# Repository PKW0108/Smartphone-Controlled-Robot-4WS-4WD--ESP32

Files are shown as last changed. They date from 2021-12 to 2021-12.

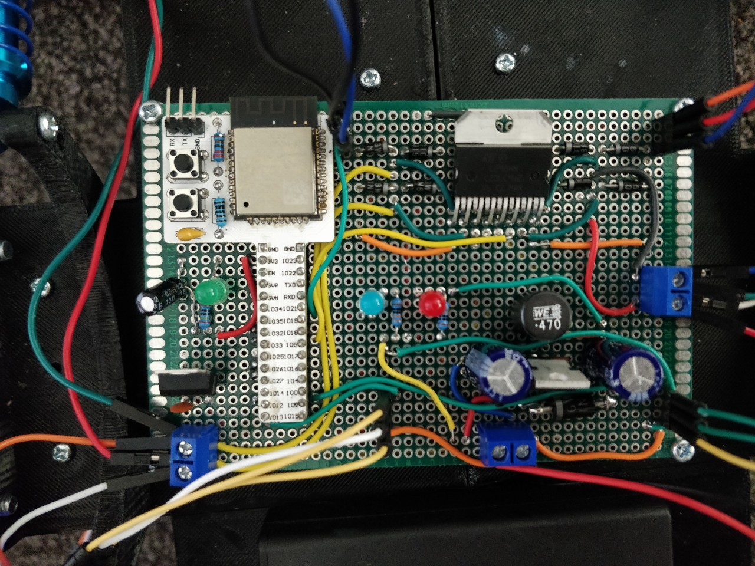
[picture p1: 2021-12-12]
PCB.jpg

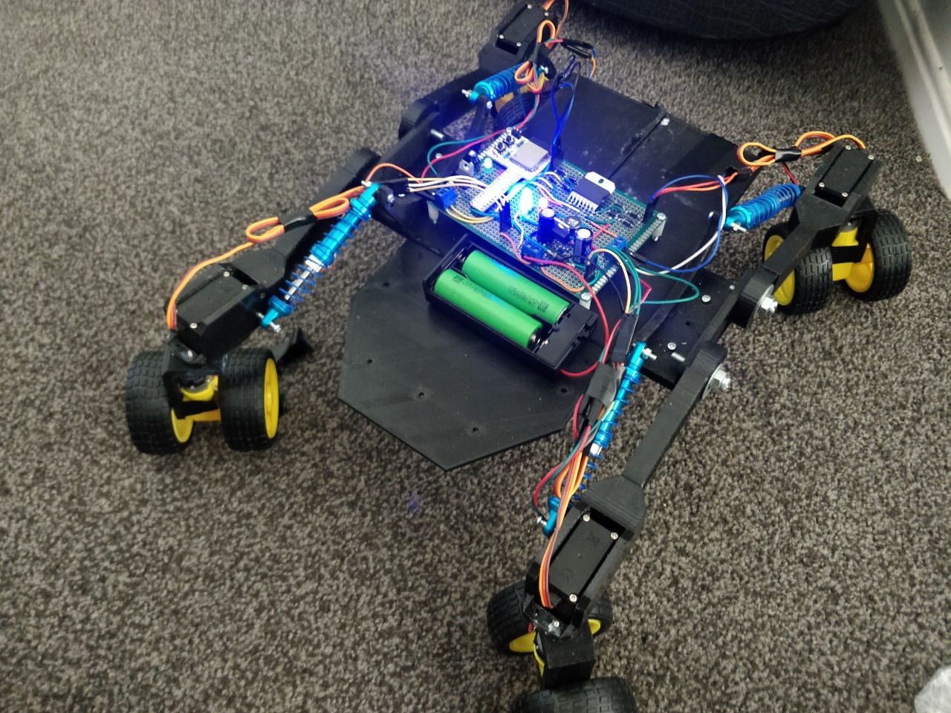
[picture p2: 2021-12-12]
Prototype Robot.jpg

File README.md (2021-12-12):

# Smartphone-Controlled-Robot-4WS-4WD--ESP32
Final Semester Project for Unitec Institue of Technology.

These are codes and 3D modellings I have created for my final semester project at Unitec Institute of Technology.

I have created an Android App using MIT App Inventor and custom PCB board that includes modules such as motor driver, buck converter and ESP32 micro-controller. The ESP32 will use its Bluetooth feature for the connection.

The Prototype Robot has 4DC motors and 4 Servo motors to meet the mobility objective. The Android App has various steering modes for the servos to move to its desired positions.

Please read the Report for more detailed analysis of this project.

Thank you

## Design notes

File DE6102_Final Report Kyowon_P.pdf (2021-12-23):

## Mobile Controlled Robot(4WD/4WS) for agricultural use

Engineering Project Report

New Zealand Diploma in Engineering (Electrical)

Department of Electrotechnology

Unitec Institute of Technology

Kyowon Park

2021

Page | i

## Declaration of Originality

This report is my own unaided work and was not copied from nor written in

collaboration with any other person.

Name: Kyowon Park

Page | ii

## Abstract

Growth in population has been a problem in farming industry for several years and the

agricultural robots started developing around 1920s. The number of workers required

on the field are becoming more insufficient around the world. There are many

agricultural robots that can perform tasks such as weed spraying, seed planting and

harvesting. My project aims to aid in agriculture by making a prototype robot that can

provide a platform for various agrobot projects to be attached. The methodology

approach was to research online to gather information on parts required and

experimenting with the information. This robot is easy for people to use by just simply

connecting with Bluetooth on smartphone. One custom built prototype PCB has all

the modules that are needed for this robot which includes modules such as

microcontroller, voltage regulators and motor driver. Advantage of this PCB is that it

can have supply voltage up to 24V DC where the robot can be easily modified for

more power, speed and longer lasting. The use of 4 servo motors for each wheel allows

the robot to have independent steering and give great advantage of moving freely in

small areas like green house. My robot aims for user to easily modify hardware and

software and not only can this be used in agriculture, but it can provide wide range of

application.

Page | iii

## Acknowledgements

I would like to thank lecturer Deepiner Sidhu for providing and giving ideas for this

project. I also would like to thank Dr Momen Bahadornejad for leading this paper.

Special thanks to my friend for lending me his 3D printer for constructing my

prototype. Thanks to my families for their support, encouragement and feedbacks for

improvements. Finally, I would like to thank lecturer Anthony Lai and Dr Nigel Yee

for attending to my presentation and demonstration session.

Page | iv

## Table of Contents

Table of Contents

Page | v

Page | vi

## List of Figures

## Chapter One: Introduction

### 1.1 Background

Agricultural robot started developing around 1920 and automatic vehicle was

implemented into agriculture between 1950s and 60s. In recent years, the population

around the world has increased rapidly where the demand for crops or food grown in

farms has increased. The problem is that the shortage of workers is increasing as time

goes on.

### 1.2 Aims and Significance of the project

The aim of my project is to build a prototype smart phone controlled robot vehicle that

will provide a platform for other projects such as LED weed detector for agricultural

use. My project will have four individual steering mechanism which allows the robot

to move freely in many directions without having to move its body. New Zealand

farmers relies on quad bikes for their farm vehicles where 80 000 to 100 000 quad

bikes are used in NZ. Despite the fast transportation and the ability to attach

accessories like sprayer, the quad bike has many problems. The driver is required to

wear safety outfit due to the harmful chemicals that herbicide contain, and the

accidents caused by the quad bikes are significant where 346 quad bike accidents

reported between 2012 to 2018.

Remote controlled vehicles can eliminate these problems and aid in the agriculture

crisis that is currently happening. Robots do not get tired and can get a lot more jobs

completed which can solve labouring issues.

### 1.3 Structure of the report

Introduction chapter has briefly articulated the background of the research and the aim

and significance of the project. The literature review briefly explains the history and

the current work of agricultural robot. The methodology chapter outlines the methods

and processes used to conduct the project. The final chapter concludes the results of

the project and provides recommendations for future studies.

## Chapter Two: Literature Review

Robotics technology including the agricultural robot is advancing. Development of

autonomous agricultural vehicles were developed in 1950s and it was not until the

1980s when the computer technology was implemented into the agricultural robot.

MAR-1 Agricultural Robot was developed in the early 1980s at Moscow Institute of

Agricultural Engineers (figure 1). MAR-1 was made for cattle-breeding industry and was

developed so it can perform autonomous entering and exiting of the site.

There are many types of agricultural robots in modern days equipped with advanced

technology. However, there lots of future works for these robots for example, robot

sensor cannot identify a certain type of plants or fruits for harvesting and fruits do not

grow from the branches identically. Most of the agricultural robots are designed for a

certain tasks and must be replaced or purchase another type of robot for different tasks.

In New Zealand, the Robotics Plus is currently developing Unmanned Ground Vehicle

(figure 2.2) to be used in the orchard field. This project is collaborated with university

of Auckland and Waikato. This vehicle aims to carry their various agricultural projects

such as the harvester and navigate through the orchard autonomously. A disadvantage

of this vehicle is that it only has two wheel steering system which can only be operated

in the large open areas.

Figure 2.1 -first model of MAR-1 (Robot, 2012)

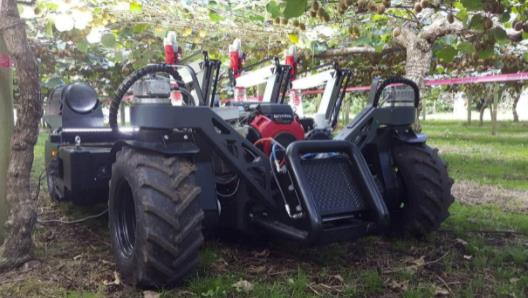
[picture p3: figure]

Figure 2.2- UGV by Robotics Plus (Harris, 2020)

## Chapter Three: Methodology

This chapter will explain the methodology that was used to complete designing and

constructing of prototype. This project was completed by using internet to gather

information and carrying out experiments. There were three main steps which were

planning, testing and evaluation.

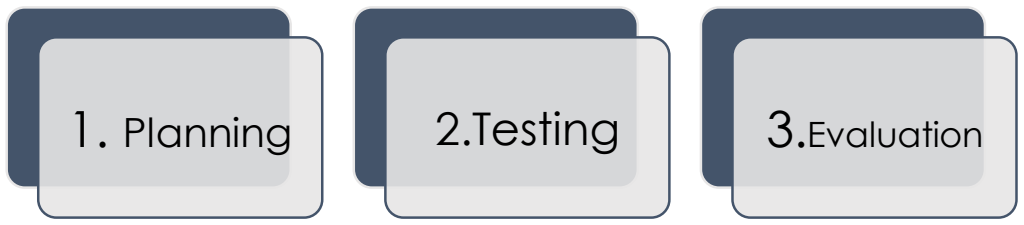
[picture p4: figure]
1. Planning; 2.Testing; 3.Evaluation

Figure 3-Project Steps

### 3.1 Planning

First step was to identify the main functions and objective for my project and then

decide on the requirements for the hardware and software. There were three main

objectives for the project which were: controlled using smart phone by Bluetooth

connection, can steer in different modes and powered by batteries. Once the objectives

were identified, I carried out research on mobile controlled robot online to gather

information on the components and design ideas of the prototype. Figure below is the

hardware design.

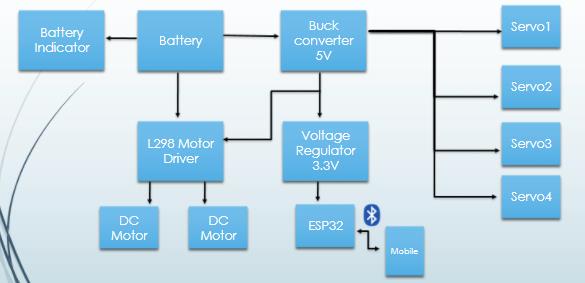
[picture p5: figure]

Figure 3.1-Hardware design

3.2 Hardware

The aim for selecting parts were to meet the budget of under $200 and be able to

perform the main functions to meet the objectives. Below is the list of the hardware

that was used to complete this project.

Part/component | Qty | Seller | Cost ($NZD)
ESP32 | 1 | Trademe | 13.99
L298 IC | 1 | Trademe | 4.99
LM2596 | 1 | DigiKey | 6.12
LD1117 3.3V | 1 | DigiKey | 0.70
Inductor 47uH 3A | 1 | DigiKey | 2.46
Dc motor with wheels | 4 | Trademe | 47.6
18650 battery holder | 1 | Trademe | 3.99
PCB board 120mm x 80mm | 1 | Trademe | 4.99
Pin header 1x3 | 4 | Trademe | 2.50
2 Pin Terminal Block(10pc) | 1 | Trademe | 3.99
Jumper Wire pack | 1 | Trademe | 8.99
330uf 35V | 2 | Surplustronics | 0.70
MG995 servo motor | 4 | Amazon | 28.09
MISC | | | 30
| | | Total 158.41
Table 3 – Component list table

### 3.2.1 Main components

TT DC motor
This is a generic 3-6V DC motor for simple robotics and affordable. There was no

need for more powerful motors for this prototype as its main objective can be made

with TT DC motors.

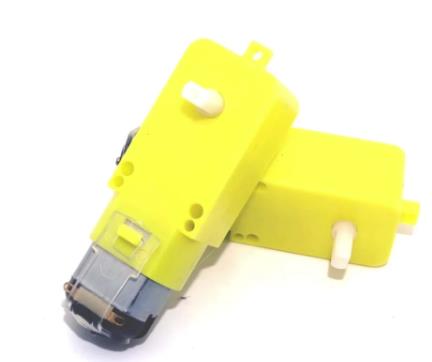
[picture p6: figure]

Figure 3.2-TT DC motor

Battery
Two Li-ion rechargeable batteries were the main supply which is 8.4V when fully

charged. The supply can be upgraded up to 24V if needed.

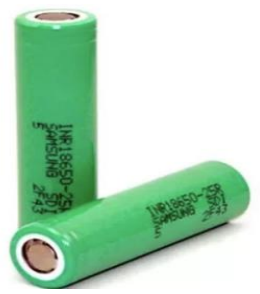
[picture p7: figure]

Figure 3.3-Li-ion 3.7V battery

LM2596

LM2596 is a simple switching power converter which can have an input up to 45V

DC and step down to 5V DC with 3A output current. Supplying more than 24V is not

recommended as the efficiency of the converter drops and will have heating problem.

The model used for this prototype is the fixed 5V version and has the efficiency of 80%

with 12V input. The 5v is required by the servo motors and the IC input of L298 motor

driver.

L298

The L298 is a dual h-bridge motor driver which can have maximum input voltage of

46V and has output current of 2A. It is recommended that diodes are used at the output

Figure-3.4LM2596 5V as this IC does not have internal protection for inductive load. This motor driver was

used so this prototype can be upgraded to 12V DC motors.

Figure 3.5-L298HN motor driver

ESP 32

The ESP 32 has built in Bluetooth and Wi-Fi feature and is known for its low power

consumption. ESP32 has the Bluetooth 4.2 and its range can be up to 50 meters

outdoors and about 10 meters indoors. It is recommended to use 10uf and 0.1uf

decoupling capacitor in parallel at the 3.3V pin to avoid brown out issues. ESP32

features 34 GPIO pins and 18 analog channels. This prototype will be using 10 analog

channels.

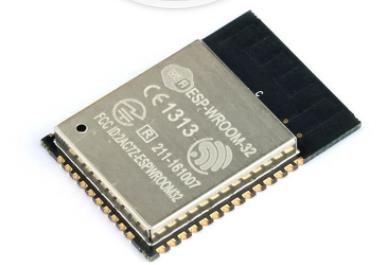
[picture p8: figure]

Figure 3.6-ESP32 wroom 32

MG995 Servo motor
By using one servo motor for each wheel can allow the robot to have individual

steering feature. MG995 is affordable and provide good amount of strength where

each motor can lift around 9.4kg/cm when operating at 5V.

Figure 3.7-MG995 servo motor

### 3.3 Software

The required software to design the prototype including android app and PCB were

OnShape, Arduino IDE, Easy EDA and MIT App inventor.

### 3.3.1 OnShape

OnShape is a free online software for 3D designing and it is very similar to Solid

works. I used this software to design the body and wheel attachments. The requirement

for the robot would be to have a ground clearance from the body of the robot and to

have four legs to hold servos and the DC motors. There are four main parts that were

designed using OnShape, base, arms, legs and holder. The base was a general flat

platform for the PCB and battery to be placed on top. Figure below is the finished 3D

design of the prototype robot.

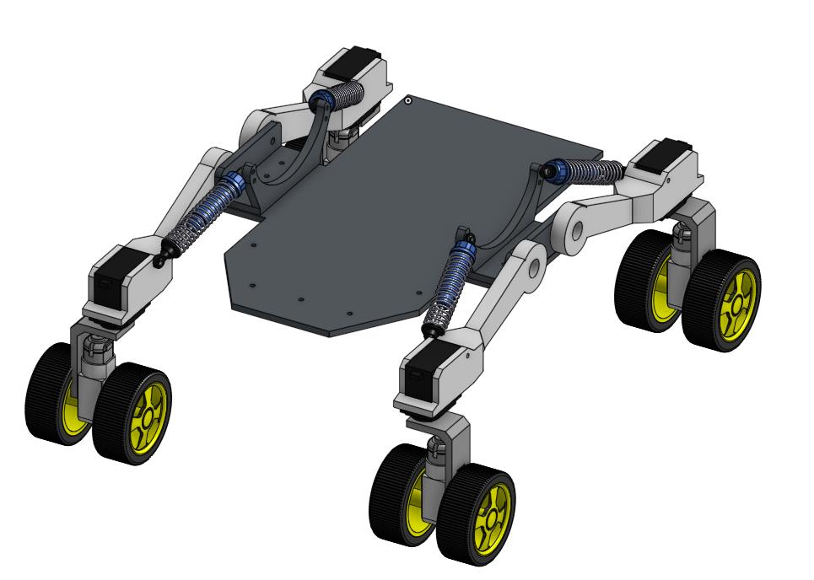
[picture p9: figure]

Figure 3.8- 3D design of the robot

### 3.3.1.1 Arms

Arms will hold the servos in place and there were errors during designing stage where

the servos did not quite fit properly at the first attempt (figure 3.9) and adjustment had

to be made.

Figure 3.9

Another issue of the design was that the arms holding the servos were unstable when

turning and this was fixed by placing the shock absorber to hold the arms and the body

together.

### 3.3.1.2 Legs

The leg is designed so that the DC motors can sit in upright position to give more

height for the robot. The leg attaches to the servos, so it can be moved according to

the servo angles.

Figure 3.11-Designed leg | Figure 3.12-assembled leg

Figure 3.10

### 3.3.1.3 Holder

Due to the length of the arm, the arms were very unstable when turning, it would

wobble around sideways without any support. The arm holder will hold the shock

absorber and the arms together to give more stability when the robot is moving. M5

screws are used for the arms and the size of the shock absorber is 1/10 RC 90mm

shock absorber. The extra holes on the horn looking design is for giving options to

change the size of shock absorber.

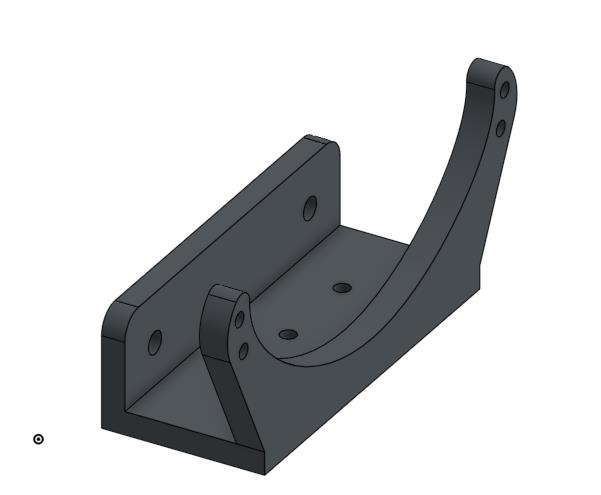
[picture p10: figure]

Figure 3.13-Designed holder

Figure 3.14-assembled holder

### 3.3.2 Arduino IDE

Arduino IDE was the software used for coding and programming the ESP32. First step

was to define variables and attach motors to ESP32 output pins. Once the motors were

attached to the pins, next step was to set up Bluetooth connection and analogue

channels for all motors (figure 3.15).

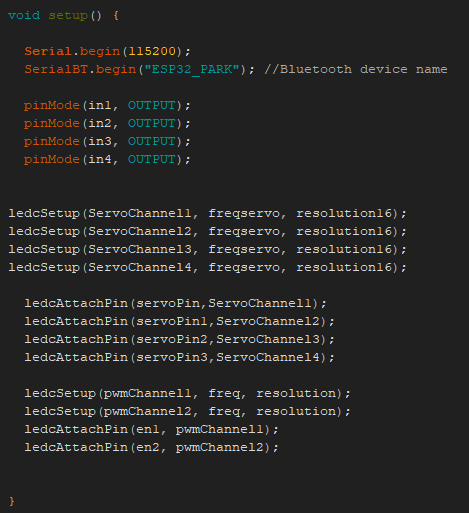
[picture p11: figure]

Figure 3.15-Setup loop

The resolution 16 bit was set up for the servo as it allows the servo to have more

steps when moving from 0 to 180 angles. To find the normal angle range of 0 to 180,

the conversion had to be made. The default pulse width range for MG995 servo motor is 500us (0 degree) to 2500us (180 degree). Using this formula, I was able to

find new range,

min = (pulse width low)/(20ms/2^16)

The calculated ranges were from 1638 to 7864. However, these values are very

difficult to identify angles of servos, so the Mapping function was used to convert

these values in to 0 to 180 range shown in figure 3.16.

Figure 3.16 - mapping of angle range

The main body (figure 3.17) of the code contains if else statements to call the

functions of motors. when there is a Bluetooth data, it will call the corresponding

function to move the motors as required.

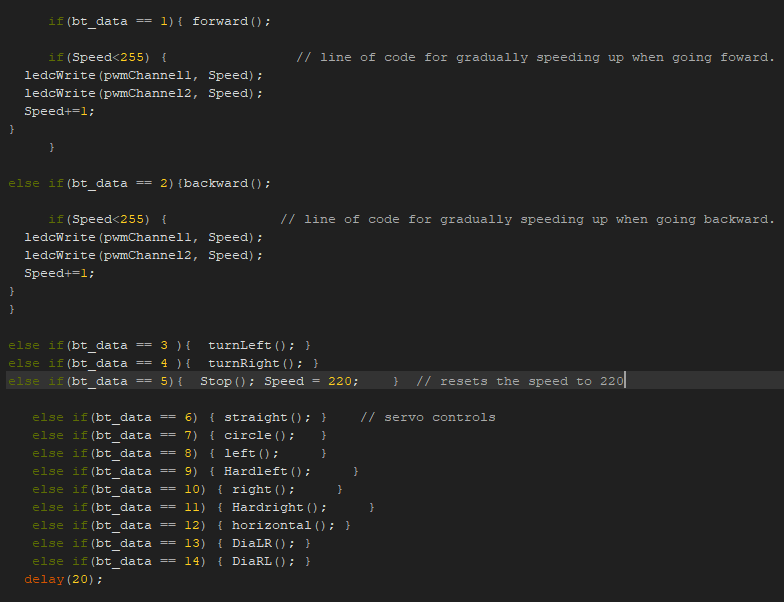
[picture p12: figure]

Figure 3.17 - Main body of code

When transferring code to the ESP32, it is important to choose the right serial port

and board. In my case I had to choose the “fire-beetle ESP32” board. Serial port

depends on the USB port the user chooses to connect.

### 3.3.3 Easy EDA

My goal was to design and assemble one PCB board half the size of an average

smartphone which consists of all the modules that were required for the prototype

robot. Before designing a schematic diagram, I used the data sheets of main

components to select right capacitors and inductors according to my desired input and

output voltages. The software I used to design schematic diagram was Easy EDA.

Once the schematic was completed, I designed the layout of the PCB. The cost for

ordering manufactured PCB was well over 100 NZD due to the SMD service and

shipping. This was going over the budget, so I chose to solder and assemble using

perfboard and through hole components.

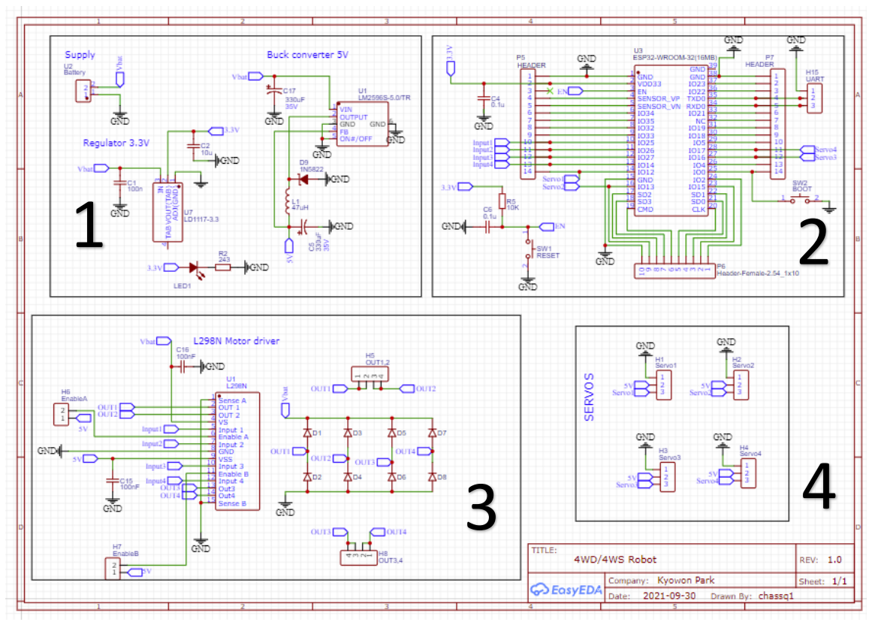
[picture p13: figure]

Figure 3.18 – Schematic Diagram designed by Easy EDA

Section 1 is the power supply modules which includes input terminal, voltage

regulator and buck converter. The capacitor and inductor value for the LM2596 was

chosen from the tables in data sheet for maximum 24V input. The LD1117 3.3V

regulator is designed according to the typical application.

Section 2 is the ESP32 with the header pins. The ESP32 has certain pin connection to

get in to transfer mode which requires to for enable pin and I0 pin to be high at the

same time and enable pin low while the I0 is still high. This can be achieved by placing switch on these pins. There is header pin connected to the Tx, Rx and GND of the

ESP32 for UART programmer.

Section 3 is the L298 motor driver. Stepped down 5V is going to the Vin of the IC and

the supply voltage directly goes to Vs for the DC motors. Outputs and enable pins are

connected accordingly to the selected ESP32 pins. 0.1uf capacitors are connected at

both input pins of IC to smooth out the DC voltage.

Section 4 is the header pins for the four servo motors.

When placing the ESP32 chip on to a PCB, it is important for the antenna part of the

ESP is not in contact with the copper layer. The layout design for the PCB is shown

in figure 3.18 below.

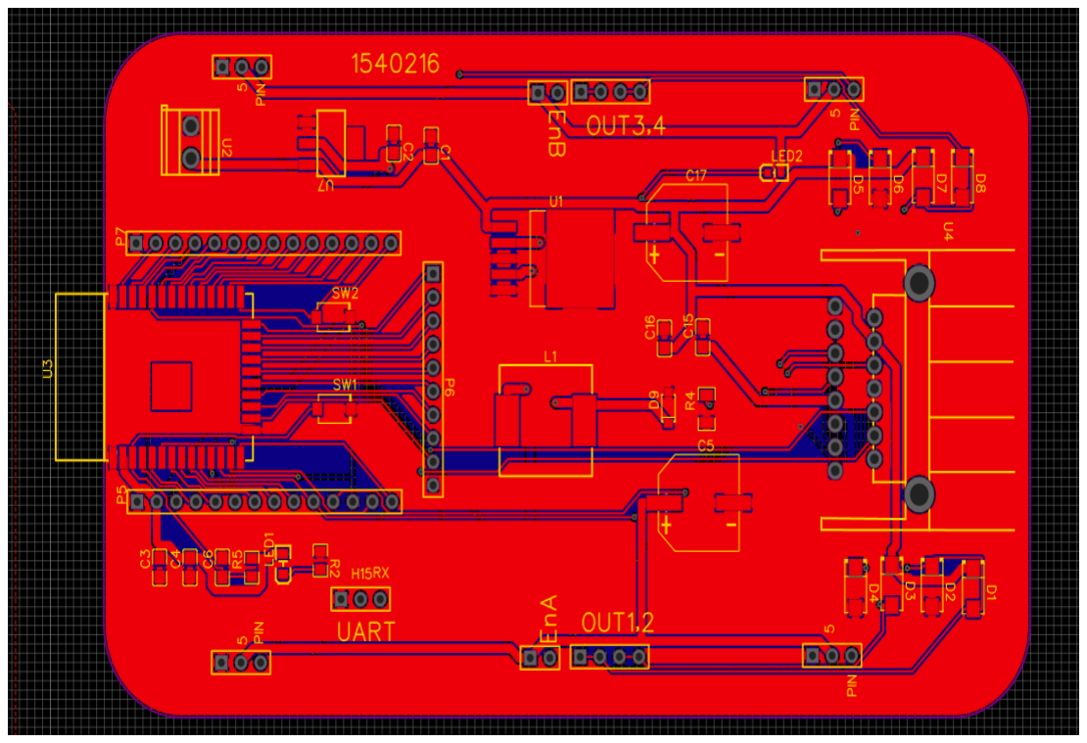
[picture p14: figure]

Figure 3.19 – Layout Design Topside

The PCB will have extra header pins around the ESP32, so it can add more servos and

motors if it is required in the future. Figure 3.20 is the generated 3D view of my PCB.

Figure 3.20 – 3D view of PCB design

### 3.3.4 MIT App Inventor

The fourth software required for this project was MIT App Inventor to create a

controlling app for a smartphone. MIT App inventor is a free online visual app

development environment currently provided by the Massachusetts Institute of

Technology. The app is programmed using block coding system. The block code will

send the Bluetooth data to the ESP32 and will be able to control the robot via

smartphone.

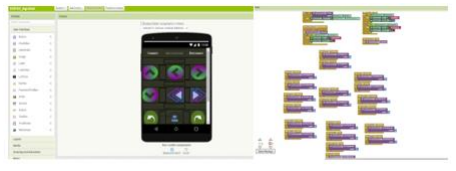
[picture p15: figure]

Figure 3.21 – MIT App Inventor designing

Figure 3.22 shows the android application that was designed by MIT App Inventor.

Touching the connect button will bring up the list of Bluetooth devices that are visible

for connection. Once Bluetooth is connected the red “Disconnected” sign will turn to

blue “Connected” sign. User can disconnect by touching the “Disconnect” button.

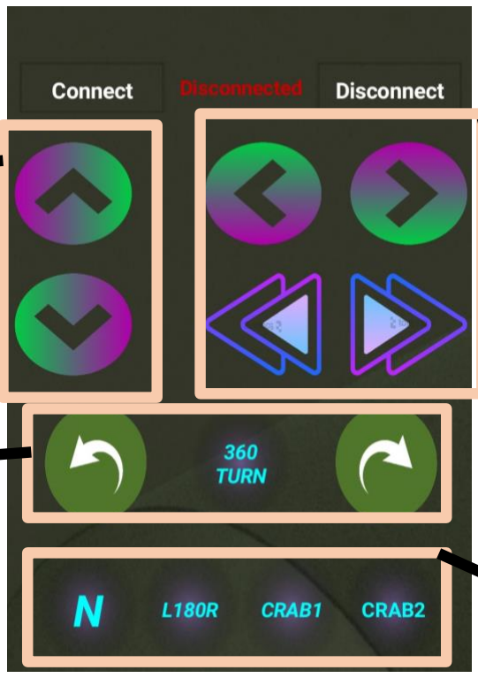
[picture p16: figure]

Figure 3.22 – Design of android App

Section 1 – these are the buttons that control the DC motors to move forward and

backward directions.

Section 2 – the top two buttons have one arrow for left and right and this is the front

two wheels steering. The bottom two buttons have double arrow, and this is for sharp

turning by including use of rear wheel steering.

Section 3 – this section is for 360 mode. When the 360Turn button is pressed, the

servos will move to the set position and by using the two buttons on each side of the

360 buttons, user can rotate the robot clock wise and anti-clock wise.

Section 4 – there are four more steering modes which includes N-normal position,

L180R-position servos to 180 degree, Crab1-position servos diagonally from right to

left and Crab2-position servos diagonally from left to right.

1

3

2

4

### 3.4 Testing

### 3.4.1 Simple Code and App

I started with simple code and simple app design to test my Bluetooth control with

Arduino Uno. There were simple example codes in Arduino IDE for LED blinking. I

tried to modify this code to Bluetooth control. After successfully getting the Bluetooth

control to work, I got myself familiarized with coding for the servos. During this

testing stage, I was able to get the ideas of how the programming was going to be

implemented to my prototype.

The testing of simple Bluetooth control using smartphone shown in figure 3.23 and

figure 3.24 below.

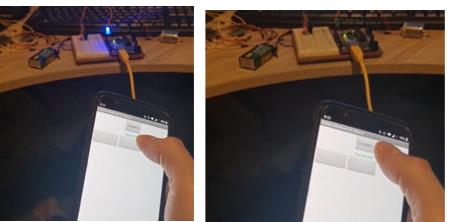
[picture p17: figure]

Figure 3.23 – Simple LED control ON and OFF

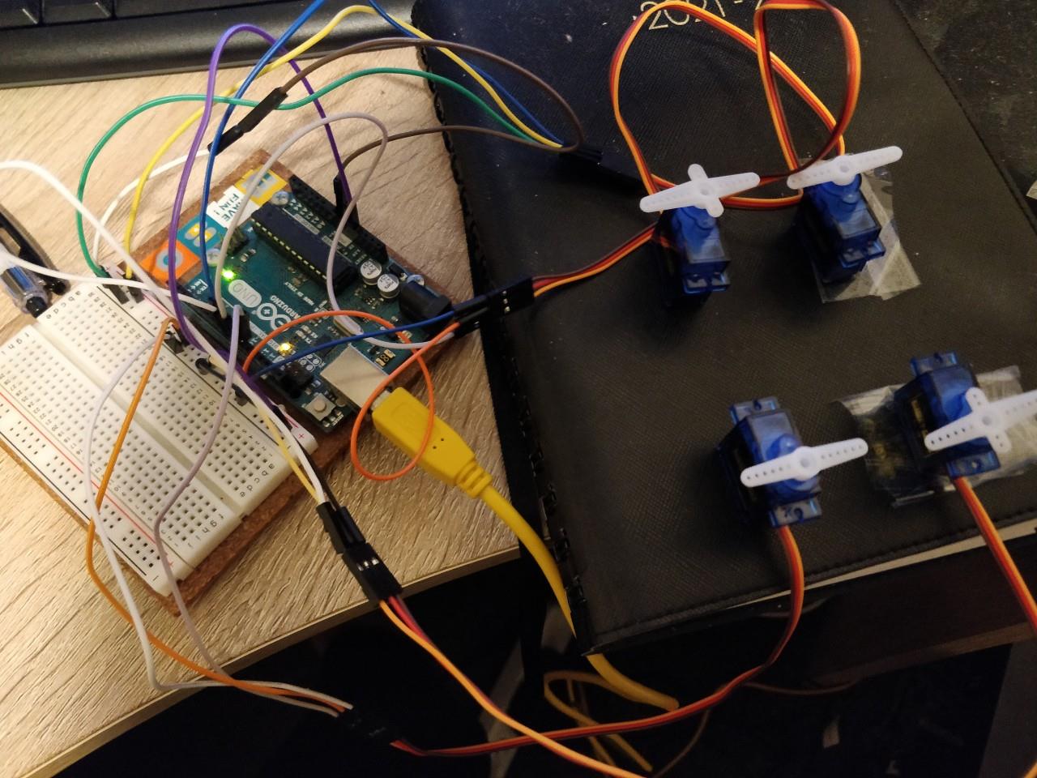
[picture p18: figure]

Figure 3.24 – Servo Control using Arduino UNO

### 3.4.2 Testing circuit

Once the components were selected and schematic diagram was drawn, the circuit test

was conducted before assembling all the components to the perfboard. I used the bread

board to set up the buck converter and the voltage regulator to confirm the output

voltages. Also, this test was to see if the circuit was correctly designed for other main

components to work correctly. For example, ESP32 requires stable 3.3V DC input and

without the correct decoupling capacitor, it will have the brown out problem which

causes the Bluetooth and Wi-Fi features on ESP32 unavailable. The circuit was

designed so the supply voltage will be stepped down by the Buck converter to 5V

which will supply the servo motors and L298 IC. The stepped down 5V will then be

regulated to 3.3V by the LD1117 for the ESP32. The figure 3.25 shows the testing of

the voltage modules. I also did an experiment of placing the wrong capacitor which

caused the LED to flicker and the noticeable noise was heard. By having the correctly

chosen components, the LED stayed on steady and no noise was heard.

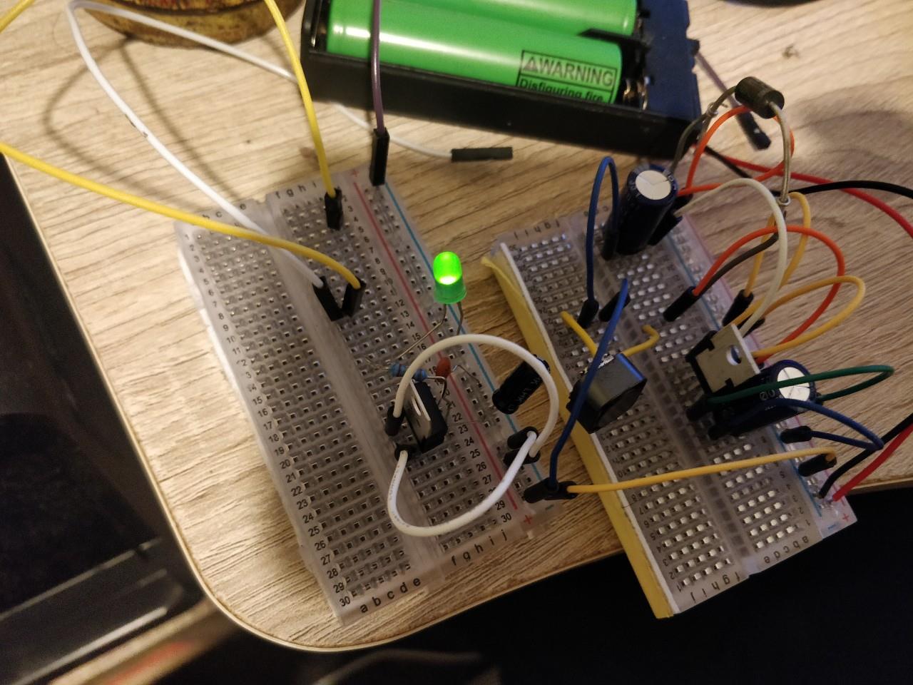
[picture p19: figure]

Figure 3.25 – Testing Buck converter and Voltage regulator

### 3.4.3 Testing PCB

After the testing circuit with bread board, I soldered all the components to the

perfboard. I carried out the continuity check using a multi meter each time I soldered

to make sure all the connections are done right and making sure the ground and supply

wires are connected properly. Once all the components were soldered on, input was

supplied by the batteries and measured the output pins of the buck converter and

voltage regulator. There are LEDs placed for each power supplies to indicate that

those are working properly.

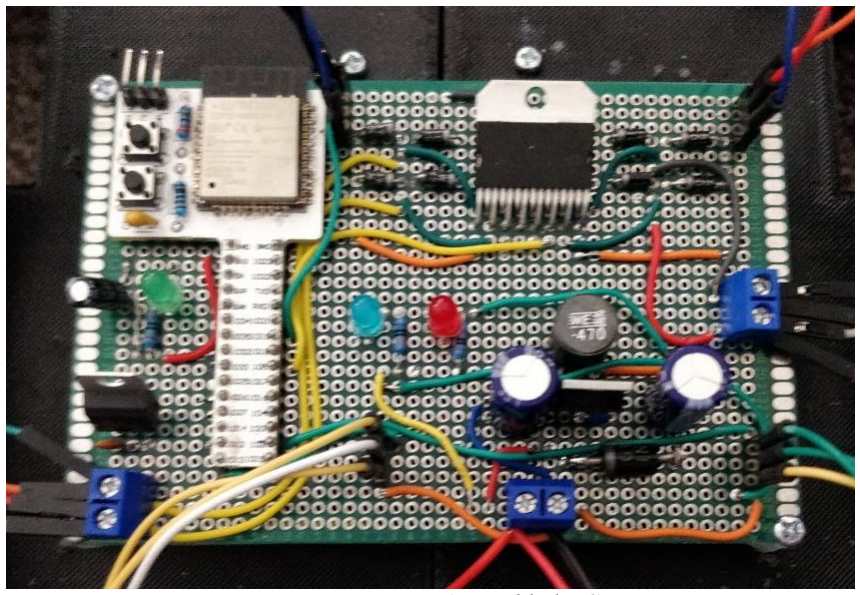
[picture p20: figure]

Figure 3.26-Assembled PCB

### 3.5 Evaluation

On completion of designing app, circuits, body and assembling the PCB, it was time

to evaluate the performance of the prototype. By supplying the power, all three LED

lights were on and the Bluetooth connection was successful with the app. The

prototype was able to move and perform all the modes of steering as the user

commands however, due to the basic DC motor with its low power, there were no

noticeable of the robot gradually speeding up. The top speed when coding was 255

and the motor was not strong enough to move when the peed was 180. The difference

in these speeds were very unnoticeable. This feature of speeding up can be used once

there is an upgrade to powerful motor.

During the evaluation phase, I also asked my family to try out using the robot. There

was common feedback of the controlling was difficult as the app was designed in

portrait orientation and a person with bigger hands have more disadvantage. Otherwise

they all agreed that it was easy to use and understand how to give commands for

various modes of steering.

### 3.5.1 Battery Indicator

This is a battery operated project and there were no indications for the users to know

about the battery level. Knowing that the minimum voltage required by the LM2596 is 4.5V, all the motors will stop working once the battery goes below 5V. During

evaluation phase, I was able to pick up this feedback and implemented the simple LED

and resistor circuit to the prototype.

The standard red, yellow and green LEDs were used which has voltage drop of around

2V. In theory, by connecting these in series all three should be lit up when more than

6V is supplied and two LEDs should be on below 6V. This way the user can be

informed by the number of LEDs that were on. Therefore, when there are only two

LEDs lit, it is indicating that the battery is supplying less than 6V and needs charging.

Figure 3.27 shows the circuit diagram of the LED battery indicator.

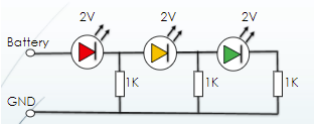
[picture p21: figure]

Figure 1.27 – Circuit diagram for battery indicator

### 3.5.2 Ackermann Steering Geometry

When a vehicle is turning around a circle, the angles of inner and outer wheels need

to be different to avoid tipping or slipping of the vehicle. Ackermann steering

geometry allows us to find these angles around a certain center point. The angles can

be found using a formula or manually drawing.

The angles can be found using the formula and parameters shown below:

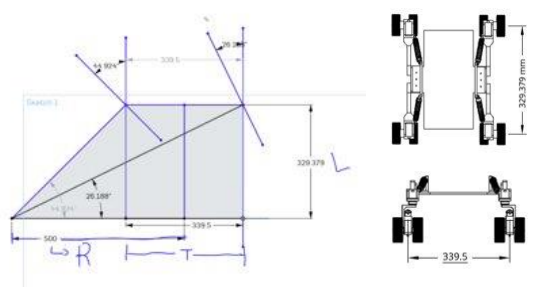
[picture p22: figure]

Figure 3.28 – parameters for finding angles

Tan a(inner) = L/(R-(T/2))

Tan a(outer) = L/(R-(T/2))

## Chapter Four: Results and Findings

### 4.1 Prototype Result

The overall construction of prototype was completed and was able to control with a

smartphone using the app that I designed. The objective of providing various steering

modes were met and this prototype can move freely in many directions. The prototype

PCB is slightly bigger than Arduino Uno board, but it was the half size of an average

smartphone. It is also designed so that it can have a supply voltage up to 24V under

$50 which means that the prototype can be easily upgraded to much powerful

prototype without changing any parts of the PCB.

Figure 2- Completed Prototype

### 4.2 Battery Indicator Result

Once circuit diagram was designed for the indicator, I have used a vero board to

assemble components and tested the board with a multi meter. Due to not having 1K

resistors, I used two 510 ohm resistors in series for each LED.

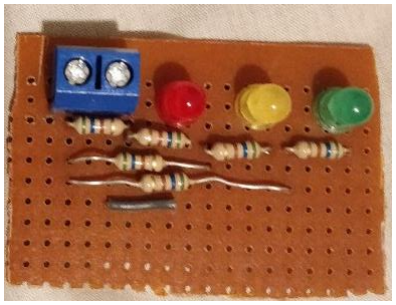
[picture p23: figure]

Figure 4.1-Soldered Battery indicator

The result for the behaviour of LEDs were shown as expected. All three lights are on

when fully charged, and two LEDs are fully on until around 5.5V and finally one LED

is on below 4V.

Figures 4.2, 4.3 and 4.4 below shows the testing of the indicator by using

potentiometer to alter input voltage.

### 4.3 Steering Results

The concept of various steering option was successfully achieved by using servo

motors for each wheel. Figures below are the photos of prototype showing different

wheel position for each mode.

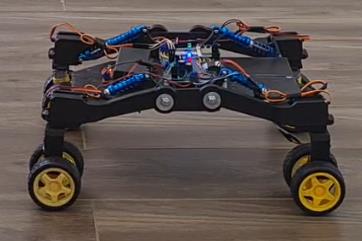
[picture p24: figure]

Figure 4.5 – Straight Mode

Figure 4.2 – Fully charged | Figure 4.3 – Needs Charging | Figure 4.4 – No power for robot

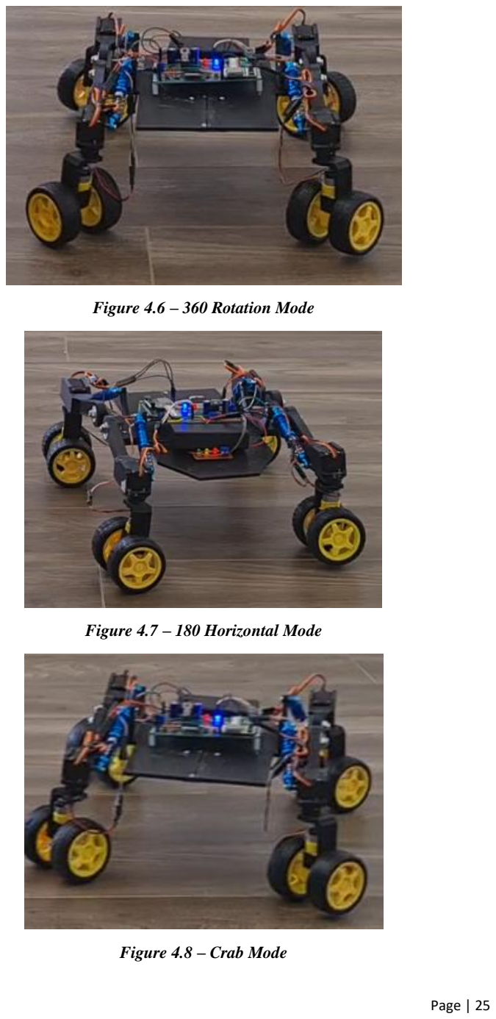
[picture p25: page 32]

Figure 4.6 – 360 Rotation Mode

Figure 4.7 – 180 Horizontal Mode

Figure 4.8 – Crab Mode

The angles found for the turning was implemented to my prototype and the distance

from center of the vehicle to the center point was set at 500mm. This distance can be

changed as required. The robot was able to turn around the center point shown by the

electrical tape. The angles calculated were correct as the robot was going around the

circle without going off the radius of 500mm. The angle for the inner wheel was 44.9

degrees and outer wheel was 63.9 degree. These values were put in to the line of code

for servos. The figure 4.9 shows the testing of the Ackermann’s steering geometry.

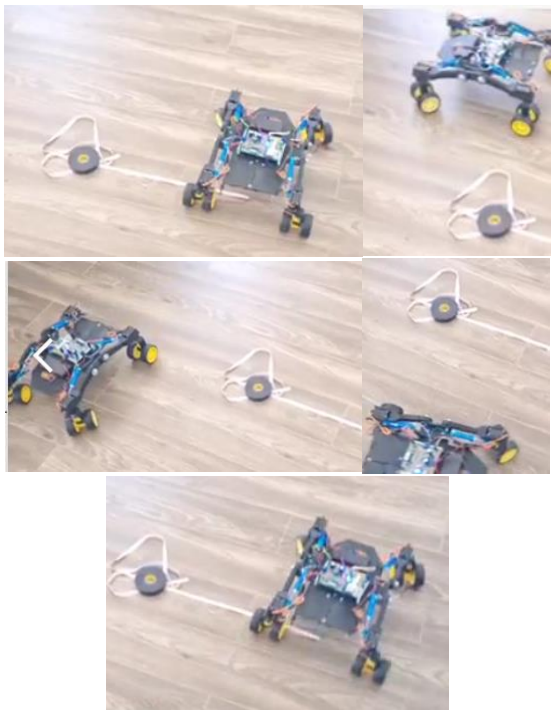
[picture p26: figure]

Figure 4.9- Testing of Ackermann Steering Geometry

## Chapter Six: Conclusion

### 6.1 Conclusion

The aim of this project was to design and construct a prototype robot to support another

project which was LED plant detecting system. These projects put together was to

provide weed detecting agricultural robot to help in the agriculture. The prototype I

have created aim to be used with many other projects and in many industries other

than agriculture.

This prototype robot is controlled remotely and can move in many direction using four

servo motors for each wheel. This project shows that a low cost PCB that is half the

size of a smartphone can deliver the performance that is required of a vehicle platform.

The PCB only costed under 50 dollars to build and it can have supply voltage of up to

24V and output of maximum of 3A.

There are many advantages using robots in many industries including the agriculture.

It is developed to solve issues of lacking workers, physical labouring and safety of

people. My prototype was designed for easy use and leaves room for easy modification

of hardware and software for adding more complex features.

### 6.2 Future Work

There are many development for this prototype. Main future work will be to upgrade

the DC motors, batteries and chassis of the prototype to aluminium for bigger platform.

ESP32 has Wi-Fi features which can be developed into controlling remotely by a

computer or a laptop instead of a smart phone. Adding a camera to the protype will

allow the users to control inside at a workstation while the robot is outside. Wi-Fi

gives a much greater range than the Bluetooth which is very advantageous. When this

prototype is upgraded with more powerful motors and bigger chassis, it can be tested

with the other projects like the LED weed detecting system.

## References

Association, R. I. (2017, December 26). Robots' benefits in the agricultural industry. Retrieved from ControlEngineering: https://www.controleng.com

Bak, L. (2020, December 9). How robots make agriculture more sustainable. Retrieved from Innovationorigins: https://innovationorigins.com

Editorial. (2019, July 18). Robotics in agriculture advantages nad disadvantages. Retrieved from Roboticsbiz: https://roboticsbiz.com

Harris, C. (2020, January 21). Stuff. Retrieved from Robot start-up Radius Robotics seeks to solve world's soil depletion: http://www.stuff.co.nz

Molloy, N. (2021, April 29). Agricultural-robotics. Retrieved from New Zealand's Vision for Agricultural Robotics: http://www.agricultural-robotics.com

N.Vamshidhar Reddy, A. V. (2016, July 4). A critical review on agricultural robots. Retrieved from ResearchGate.

Robot, M.-1. A. (2012, May 1). shvachko. Retrieved from http://www.shavchko.net

Wilsong, L. (2019, August 30). Quad bike injury data raises questions about children, older riders. Retrieved from Stuff: https://www.stuff.co.nz

## Appendices

Appendix 1: Graduate Attributes, Definitions and Evidences of Achievement

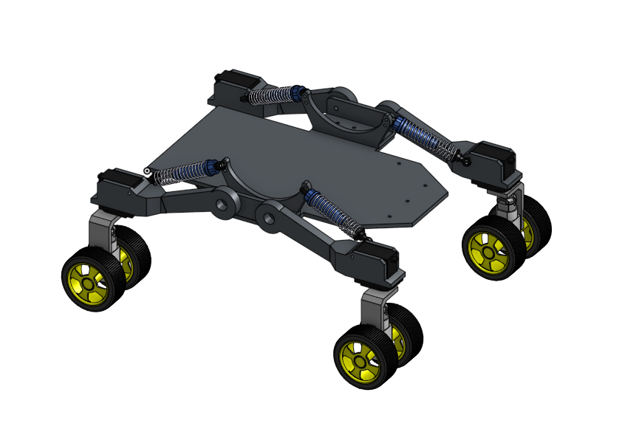
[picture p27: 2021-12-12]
3D model of project.PNG

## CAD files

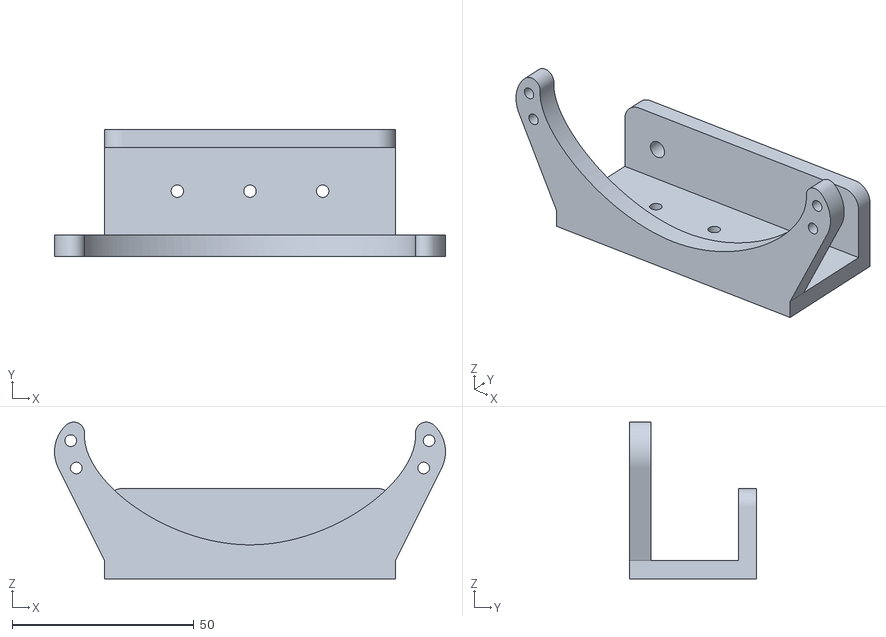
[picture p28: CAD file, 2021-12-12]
Leg attachment part.stl
107.6 x 35.0 x 43.2

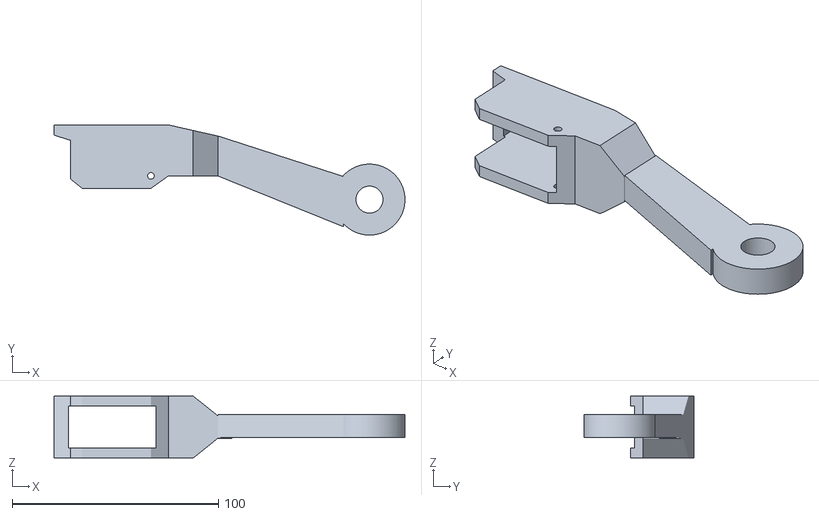
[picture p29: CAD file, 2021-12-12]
Arm part.stl
170.1 x 53.4 x 30.0

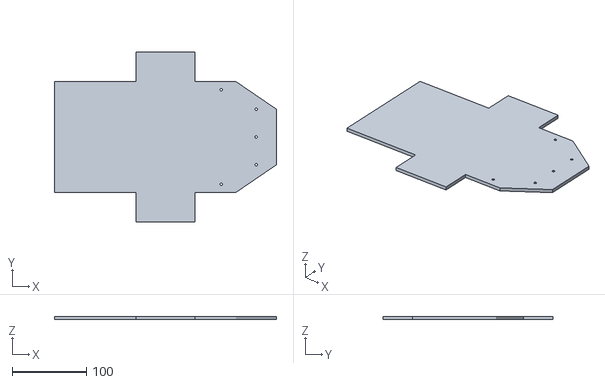
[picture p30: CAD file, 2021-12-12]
Base part.stl
300.0 x 230.0 x 4.50

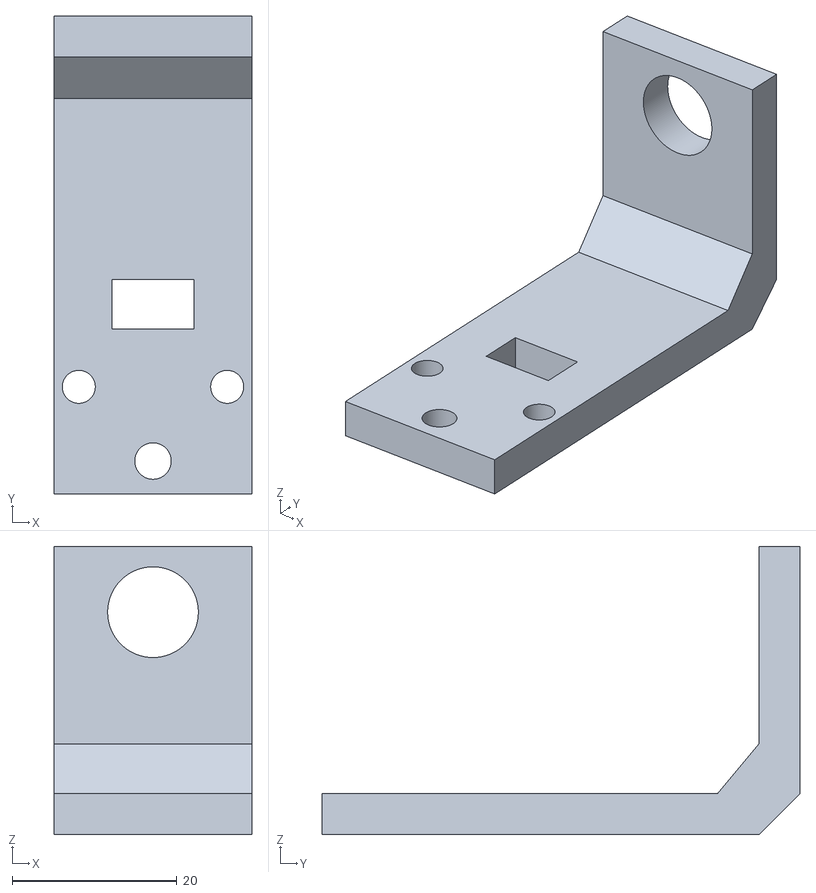
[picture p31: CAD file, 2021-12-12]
DC motor leg part.stl
24.0 x 58.0 x 35.0

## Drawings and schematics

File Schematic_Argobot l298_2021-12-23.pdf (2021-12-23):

## Regulator 3.3V

Supply | Buck converter 5V

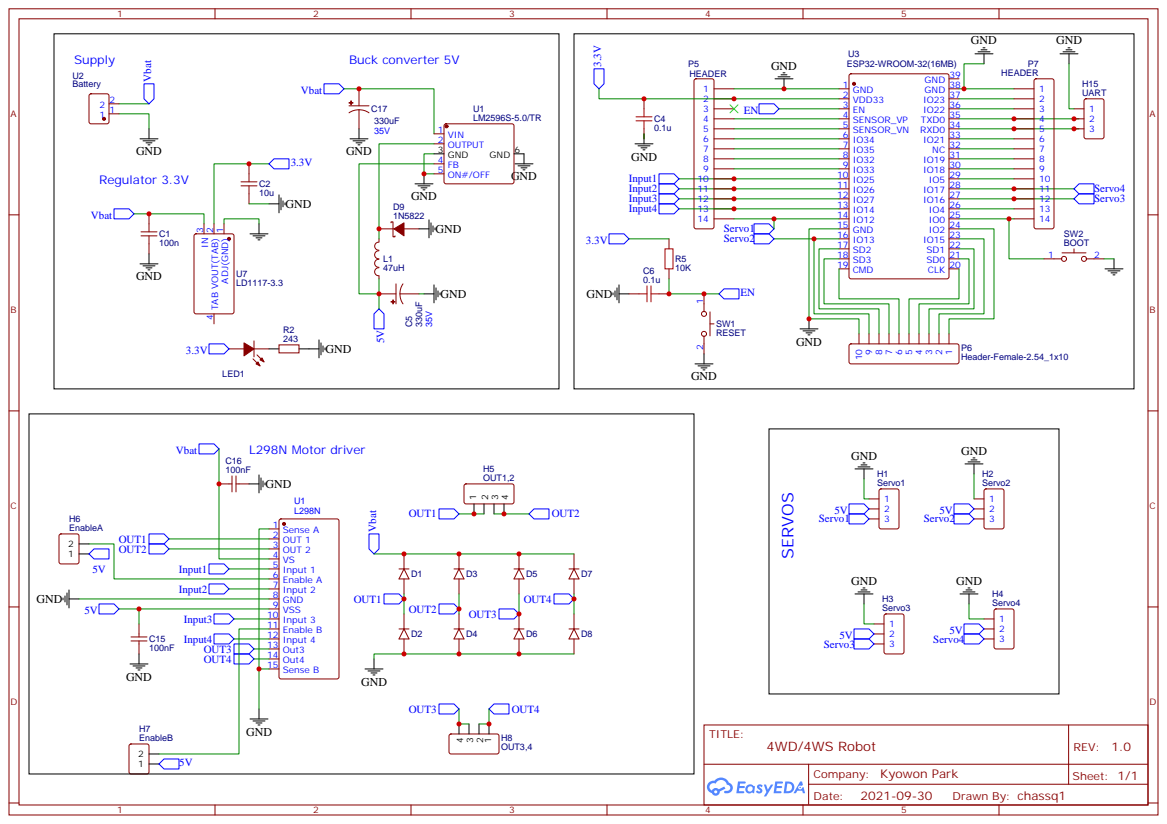
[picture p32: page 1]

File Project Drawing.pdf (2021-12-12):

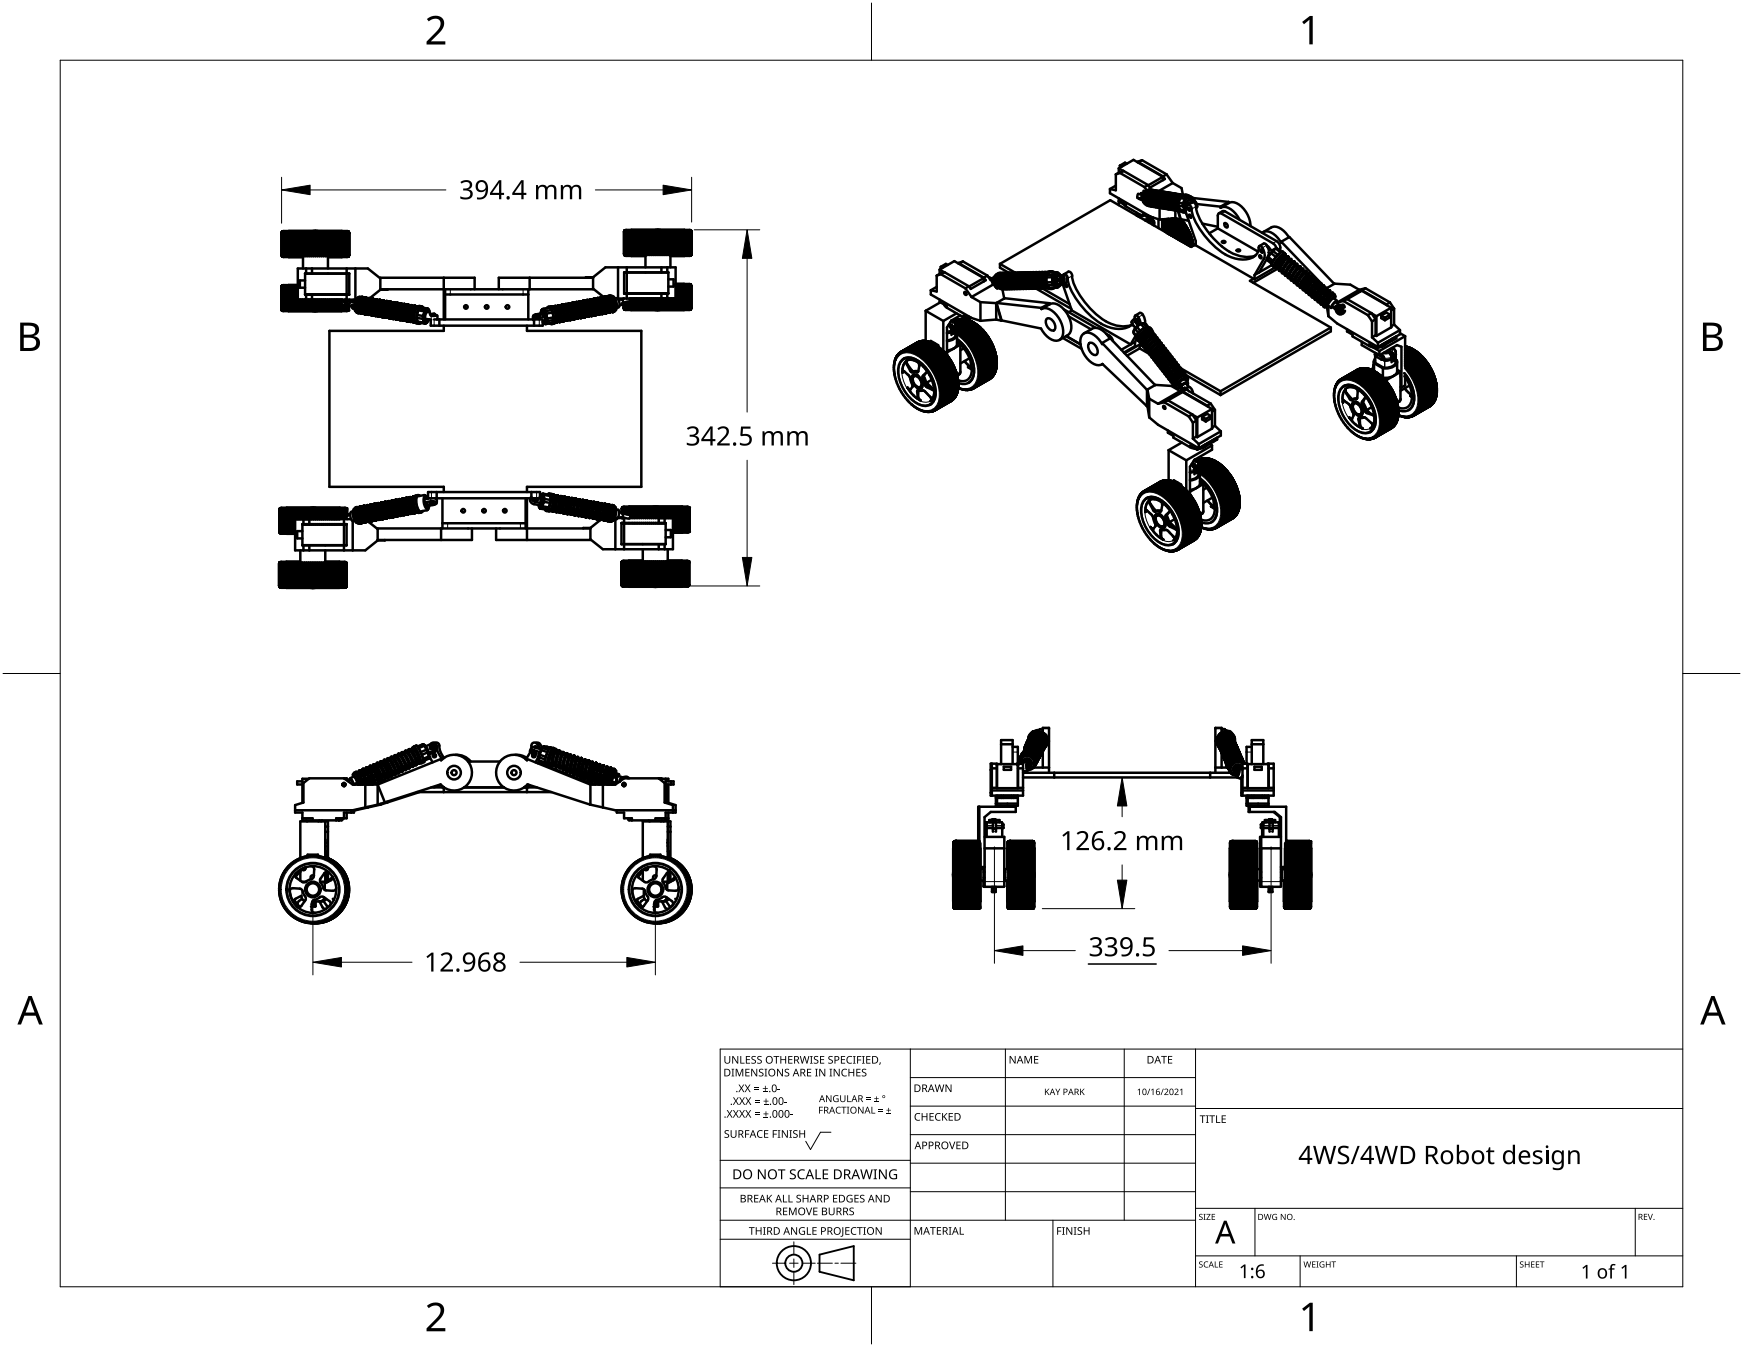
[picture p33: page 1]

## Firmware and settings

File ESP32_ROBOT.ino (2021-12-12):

#include "BluetoothSerial.h"

BluetoothSerial SerialBT;

static const int servoPin =13 ;  
static const int servoPin1 =2;                 
static const int servoPin2 =18;
static const int servoPin3 =19;

const int in1 = 26; 
const int in2 = 27; 
const int in3 = 33;
const int in4 = 32;
const int en1 = 5;
const int en2 = 12;

const int freq = 3000;
const int pwmChannel1 = 0;
const int pwmChannel2 = 1;
const int resolution = 8;

int bt_data = 0;
int Speed=220;   // original speed

int angle  = 100;   // when the robot is powered on, the servos go to straight position
int angle2 = 90;
int angle3 = 95;
int angle4 = 90;

const int freqservo = 50;
const int ServoChannel1 = 2;
const int ServoChannel2 = 3;
const int ServoChannel3 = 4;
const int ServoChannel4 = 5;
const int resolution16 = 16;

void setup() {
  
  Serial.begin(115200);
  SerialBT.begin("ESP32_PARK"); //Bluetooth device name
  
  pinMode(in1, OUTPUT); 
  pinMode(in2, OUTPUT);
  pinMode(in3, OUTPUT);
  pinMode(in4, OUTPUT);


ledcSetup(ServoChannel1, freqservo, resolution16);
ledcSetup(ServoChannel2, freqservo, resolution16);
ledcSetup(ServoChannel3, freqservo, resolution16);
ledcSetup(ServoChannel4, freqservo, resolution16);

  ledcAttachPin(servoPin,ServoChannel1);
  ledcAttachPin(servoPin1,ServoChannel2);
  ledcAttachPin(servoPin2,ServoChannel3);
  ledcAttachPin(servoPin3,ServoChannel4); 

  ledcSetup(pwmChannel1, freq, resolution);
  ledcSetup(pwmChannel2, freq, resolution);
  ledcAttachPin(en1, pwmChannel1);
  ledcAttachPin(en2, pwmChannel2);


}

void loop() {

    if (SerialBT.available()){
     bt_data = SerialBT.read();
     SerialBT.print(bt_data);
    }

  ledcWrite(pwmChannel1, Speed);
  ledcWrite(pwmChannel2, Speed);
  
  ledcWrite(2,map(angle,  0, 180, 1638, 7864)); // converting to 0 - 180 degrees
  ledcWrite(3,map(angle2, 0, 180, 1638, 7864));
  ledcWrite(4,map(angle3, 0, 180, 1638, 7864));
  ledcWrite(5,map(angle4, 0, 180, 1638, 7864));

  
     if(bt_data == 1){ forward(); 

     if(Speed<255) {                // line of code for gradually speeding up when going foward.
  ledcWrite(pwmChannel1, Speed);   
  ledcWrite(pwmChannel2, Speed); 
  Speed+=1;
}
     } 
           
else if(bt_data == 2){backward(); 

     if(Speed<255) {              // line of code for gradually speeding up when going backward.
  ledcWrite(pwmChannel1, Speed);   
  ledcWrite(pwmChannel2, Speed); 
  Speed+=1;
}
}
                      
else if(bt_data == 3 ){  turnLeft(); }                       
else if(bt_data == 4 ){  turnRight(); }                      
else if(bt_data == 5){  Stop(); Speed = 220;    }  // resets the speed to 220

   else if(bt_data == 6) { straight(); }    // servo controls
   else if(bt_data == 7) { circle();   }
   else if(bt_data == 8) { left();     }
   else if(bt_data == 9) { Hardleft();     }
   else if(bt_data == 10) { right();     }
   else if(bt_data == 11) { Hardright();     }
   else if(bt_data == 12) { horizontal(); }
   else if(bt_data == 13) { DiaLR(); }
   else if(bt_data == 14) { DiaRL(); } 
  delay(20);  

  }


  void forward(){  //forword
digitalWrite(in1, HIGH); //Right Motor forword Pin 
digitalWrite(in2, LOW);  //Right Motor backword Pin 
digitalWrite(in3, LOW);  //Left Motor backword Pin 
digitalWrite(in4, HIGH); //Left Motor forword Pin 

}

void backward(){ //backword
digitalWrite(in1, LOW);  //Right Motor forword Pin 
digitalWrite(in2, HIGH); //Right Motor backword Pin 
digitalWrite(in3, HIGH); //Left Motor backword Pin 
digitalWrite(in4, LOW);  //Left Motor forword Pin 

}

void turnRight(){ //turnRight
digitalWrite(in1, LOW);  //Right Motor forword Pin 
digitalWrite(in2, HIGH); //Right Motor backword Pin  
digitalWrite(in3, LOW);  //Left Motor backword Pin 
digitalWrite(in4, HIGH); //Left Motor forword Pin 
}

void turnLeft(){ //turnLeft
digitalWrite(in1, HIGH); //Right Motor forword Pin 
digitalWrite(in2, LOW);  //Right Motor backword Pin 
digitalWrite(in3, HIGH); //Left Motor backword Pin 
digitalWrite(in4, LOW);  //Left Motor forword Pin 
}

void Stop(){ //stop
digitalWrite(in1, LOW); //Right Motor forword Pin 
digitalWrite(in2, LOW); //Right Motor backword Pin 
digitalWrite(in3, LOW); //Left Motor backword Pin 
digitalWrite(in4, LOW); //Left Motor forword Pin 
}  

void straight() {
  angle  = 100;
  angle2 = 90;
  angle3 = 95;
  angle4 = 90;
}
void circle() {
  angle  = 55;
  angle2 = 135;
  angle3 = 50;
  angle4 = 135;
  
}

void left() {
  angle  = 74;
  angle2 = 45;
  angle3 = 95;
  angle4 = 90;
}

void Hardleft() {
  angle  = 74;
  angle2 = 45;
  angle3 = 140;
  angle4 = 116;
}

void right() {
  angle  = 145;
  angle2 = 116;
  angle3 = 95;
  angle4 = 90;
}

void Hardright() {
  angle  = 145;
  angle2 = 116;
  angle3 = 69;
  angle4 = 45;
}
void horizontal() {
  angle  = 0;
  angle2 = 0;
  angle3 = 0;
  angle4 = 0;
}

void DiaLR() {
  angle  = 145;
  angle2 = 135;
  angle3 = 140;
  angle4 = 135;
}

void DiaRL() {
  angle  = 55;
  angle2 = 45;
  angle3 = 50;
  angle4 = 45;
}
